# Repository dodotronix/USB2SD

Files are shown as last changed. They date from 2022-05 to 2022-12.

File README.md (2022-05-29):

# Bridge - USB TO SD Card 
This project is originally for 3d printer Anet. As the movement of the extruder
is shredded, when printing via USB serial connection. The shredding can be
avoided, when printing from the SDcard. This is not so confortable, because the
card has to be unplugged, inserted into the card reader to store the print data
and returned to the printer.

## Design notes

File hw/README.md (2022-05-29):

# HW design notes

## BOM list
| Component name  | Type | Purchase | Notes |
| :---: | :---:| :---: | :---: |
| [SN3257QPWRQ1](https://cz.mouser.com/ProductDetail/Texas-Instruments/SN3257QPWRQ1?qs=%252B6g0mu59x7JRD99NE57pzA%3D%3D) | analog mux | :white_square_button: | |
| [10118194-0001LF](https://cz.mouser.com/ProductDetail/Amphenol-FCI/10118194-0001LF?qs=Ywefl8B65e4FIdY8OWfRQA%3D%3D) | usb connector SMD | :white_square_button: | | 
| [TOL-09419](https://cz.mouser.com/ProductDetail/SparkFun/TOL-09419?qs=WyAARYrbSnZj2Gc3mUSwiw%3D%3D) | sd sniffer | :white_square_button: | |
| [USB2642-I/ML](https://cz.mouser.com/ProductDetail/Microchip-Technology/USB2642-I-ML?qs=QaDcGzfVzPPIqPyBH4Ei1Q%3D%3D) | usb bridge | :white_square_button: | |

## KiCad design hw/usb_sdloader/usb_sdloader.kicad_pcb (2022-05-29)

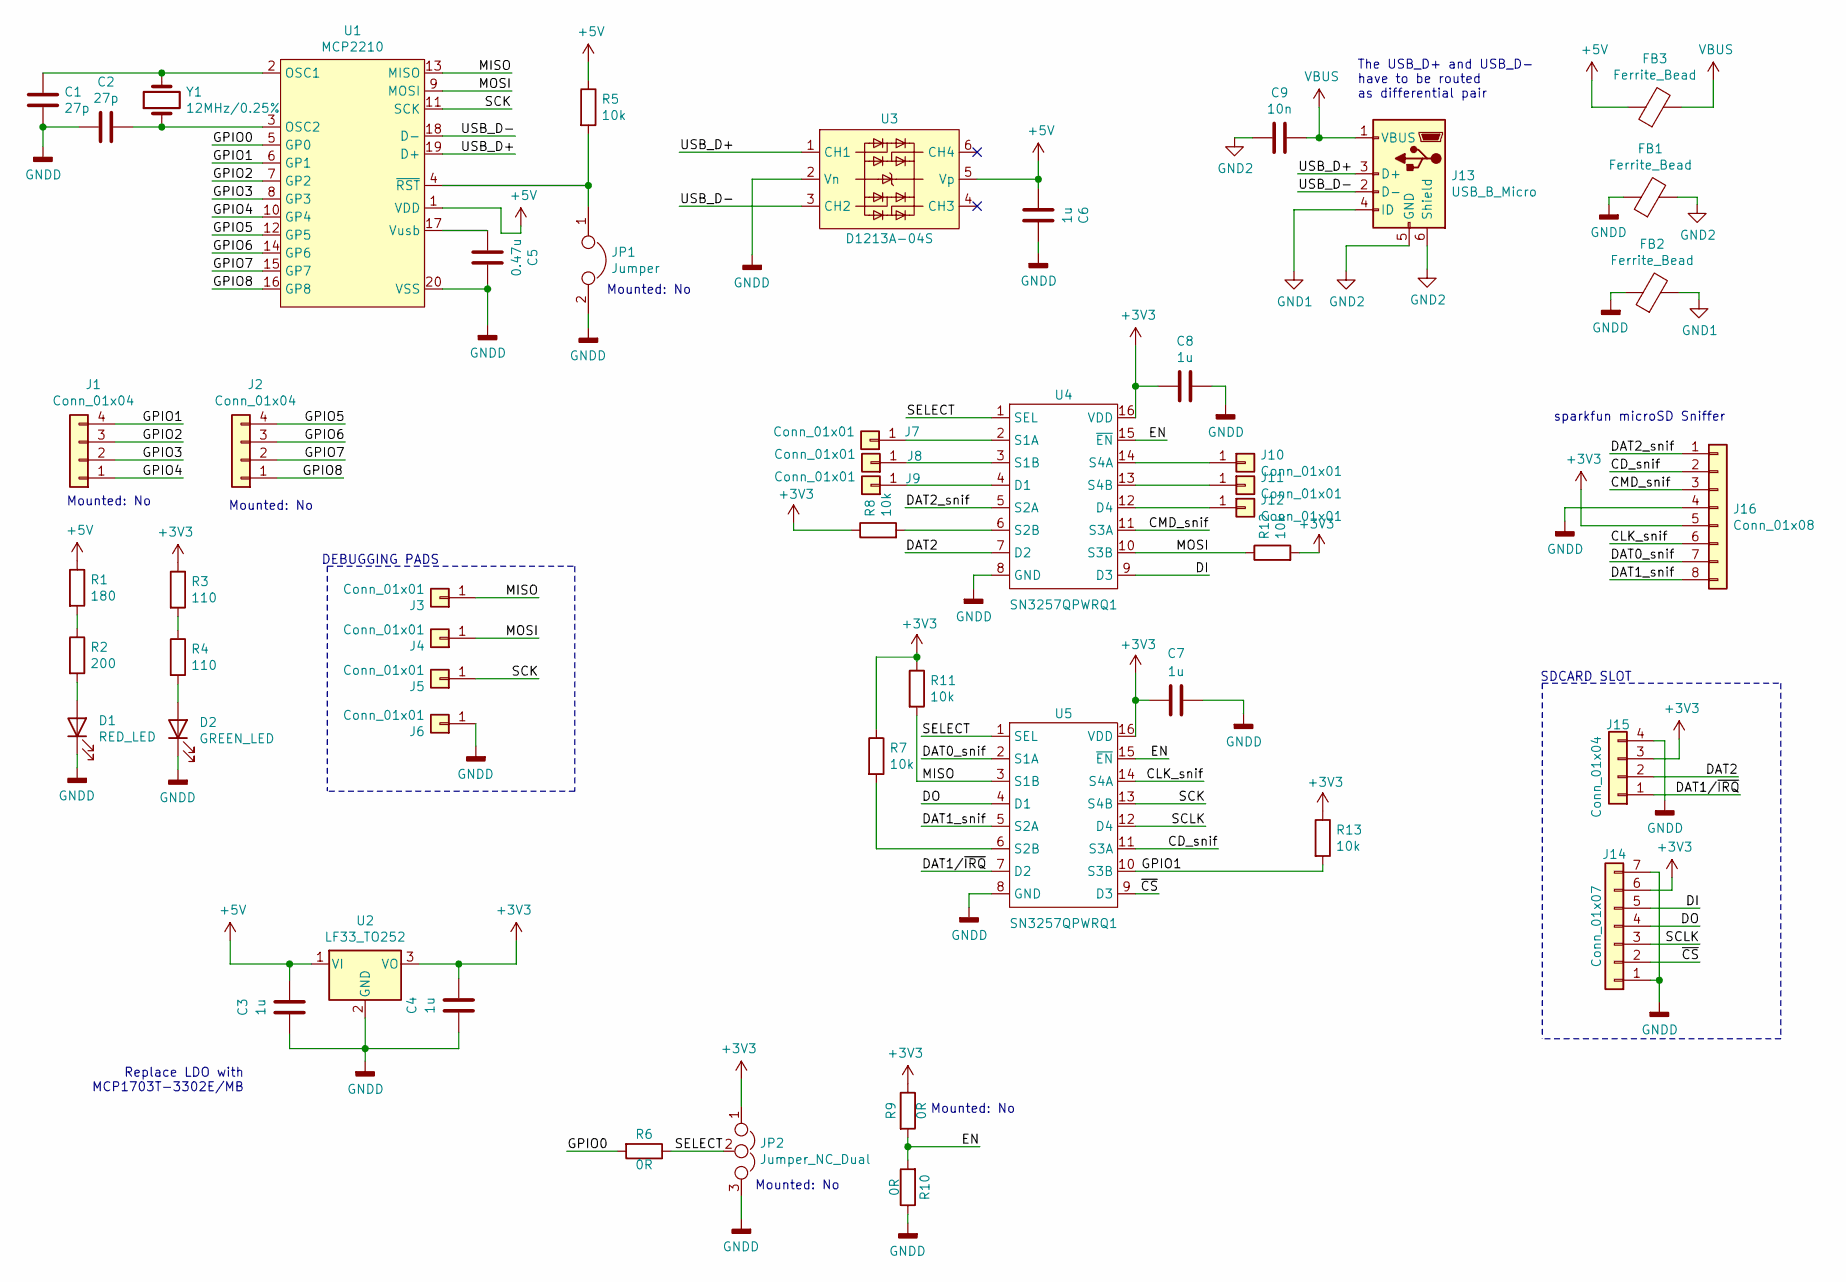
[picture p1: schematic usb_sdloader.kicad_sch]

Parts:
C1, C2: 27p; C_0805_2012Metric_Pad1.18x1.45mm_HandSolder
C3, C4, C6, C7, C8: 1u; C_0805_2012Metric_Pad1.18x1.45mm_HandSolder
C5: 0.47u; C_0805_2012Metric_Pad1.18x1.45mm_HandSolder
C9: 10n; C_0603_1608Metric_Pad1.08x0.95mm_HandSolder
D1: RED_LED; LED_1206_3216Metric_Pad1.42x1.75mm_HandSolder
D2: GREEN_LED; LED_1206_3216Metric_Pad1.42x1.75mm_HandSolder
FB1, FB2, FB3: Ferrite_Bead; L_0603_1608Metric_Pad1.05x0.95mm_HandSolder
J1, J2, J15: Conn_01x04; PinHeader_1x04_P2.54mm_Vertical_SMD_Pin1Left
J3, J4, J5, J6, J7, J8, J9, J10, J11, J12: Conn_01x01; TestPoint_Pad_D2.0mm
J13: USB_B_Micro; USB_Micro-B_Molex-105017-0001
J14: Conn_01x07; PinHeader_1x07_P2.54mm_Vertical_SMD_Pin1Left
J16: Conn_01x08; PinHeader_1x08_P2.54mm_Vertical_SMD_Pin1Left
JP1: Jumper; PinHeader_1x02_P2.54mm_Vertical_SMD_Pin1Left
JP2: Jumper_NC_Dual; PinHeader_1x03_P2.54mm_Vertical_SMD_Pin1Left
R1: 180; R_0805_2012Metric_Pad1.20x1.40mm_HandSolder
R2: 200; R_0805_2012Metric_Pad1.20x1.40mm_HandSolder
R3, R4: 110; R_0805_2012Metric_Pad1.20x1.40mm_HandSolder
R5, R7, R8, R11, R12, R13: 10k; R_0805_2012Metric_Pad1.20x1.40mm_HandSolder
R6, R9, R10: 0R; R_0603_1608Metric_Pad0.98x0.95mm_HandSolder
U1: MCP2210; SOIC-20W_7.5x12.8mm_P1.27mm
U2: LF33_TO252; TO-252-2
U3: D1213A-04S; SOT-363_SC-70-6_Handsoldering
U4, U5: SN3257QPWRQ1; TSSOP-16_4.4x5mm_P0.65mm
Y1: 12MHz/0.25%; Crystal_SMD_HC49-SD_HandSoldering

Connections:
+3V3: C4.1, C7.2, C8.2, J14.6, J15.3, J16.5, JP2.1, R3.1, R7.1, R8.1, R9.1, R11.1, R12.2, R13.1, U2.3 (VO), U4.16 (VDD), U5.16 (VDD)
+5V: C3.1, C6.2, FB3.1, R1.1, R5.1, U1.1 (VDD), U2.1 (VI), U3.5 (Vp)
/CD_snif: J16.2, U5.11 (S3A)
/CLK_snif: J16.6, U5.14 (S4A)
/CMD_snif: J16.3, U4.11 (S3A)
/DAT0_snif: J16.7, U5.2 (S1A)
/DAT1_snif: J16.8, U5.5 (S2A)
/DAT1/~IRQ: J15.1, U5.7 (D2)
/DAT2: J15.2, U4.7 (D2)
/DAT2_snif: J16.1, U4.5 (S2A)
/DI: J14.5, U4.9 (D3)
/DO: J14.4, U5.4 (D1)
/EN: R9.2, R10.2, U4.15 (~EN), U5.15 (~EN)
/GPIO0: R6.2, U1.5 (GP0)
/GPIO1: J1.4, R13.2, U1.6 (GP1), U5.10 (S3B)
/GPIO2: J1.3, U1.7 (GP2)
/GPIO3: J1.2, U1.8 (GP3)
/GPIO4: J1.1, U1.10 (GP4)
/GPIO5: J2.4, U1.12 (GP5)
/GPIO6: J2.3, U1.14 (GP6)
/GPIO7: J2.2, U1.15 (GP7)
/GPIO8: J2.1, U1.16 (GP8)
/MISO: J3.1, R11.2, U1.13 (MISO), U5.3 (S1B)
/MOSI: J4.1, R12.1, U1.9 (MOSI), U4.10 (S3B)
/SCK: J5.1, U1.11 (SCK), U5.13 (S4B)
/SCLK: J14.3, U5.12 (D4)
/SELECT: JP2.2, R6.1, U4.1 (SEL), U5.1 (SEL)
/USB_D+: J13.3 (D+), U1.19 (D+), U3.1 (CH1)
/USB_D-: J13.2 (D-), U1.18 (D-), U3.3 (CH2)
/~CS: J14.2, U5.9 (D3)
GND1: FB2.2, J13.4 (ID)
GND2: C9.2, FB1.2, J13.5 (GND), J13.6 (Shield)
GNDD: C1.2, C2.1, C3.2, C4.2, C5.1, C6.1, C7.1, C8.1, D1.1 (K), D2.1 (K), FB1.1, FB2.1, J6.1, J14.1, J14.7, J15.4, J16.4, JP1.2, JP2.3, R10.1, U1.20 (VSS), U2.2 (GND), U3.2 (Vn), U4.8 (GND), U5.8 (GND)
unnamed: C1.1, U1.2 (OSC1), Y1.2
unnamed: C2.2, U1.3 (OSC2), Y1.1
unnamed: C5.2, U1.17 (Vusb)
unnamed: D1.2 (A), R2.2
unnamed: D2.2 (A), R4.2
unnamed: J7.1, U4.2 (S1A)
unnamed: J8.1, U4.3 (S1B)
unnamed: J9.1, U4.4 (D1)
unnamed: J10.1, U4.14 (S4A)
unnamed: J11.1, U4.13 (S4B)
unnamed: J12.1, U4.12 (D4)
unnamed: JP1.1, R5.2, U1.4 (~RST)
unnamed: R1.2, R2.1
unnamed: R3.2, R4.1
unnamed: R7.2, U5.6 (S2B)
unnamed: R8.2, U4.6 (S2B)
VBUS: C9.1, FB3.2, J13.1 (VBUS)

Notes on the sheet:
Mounted: No
Replace LDO with MCP1703T-3302E/MB
DEBUGGING PADS
The USB_D+ and USB_D- have to be routed as differential pair
SDCARD SLOT
sparkfun microSD Sniffer

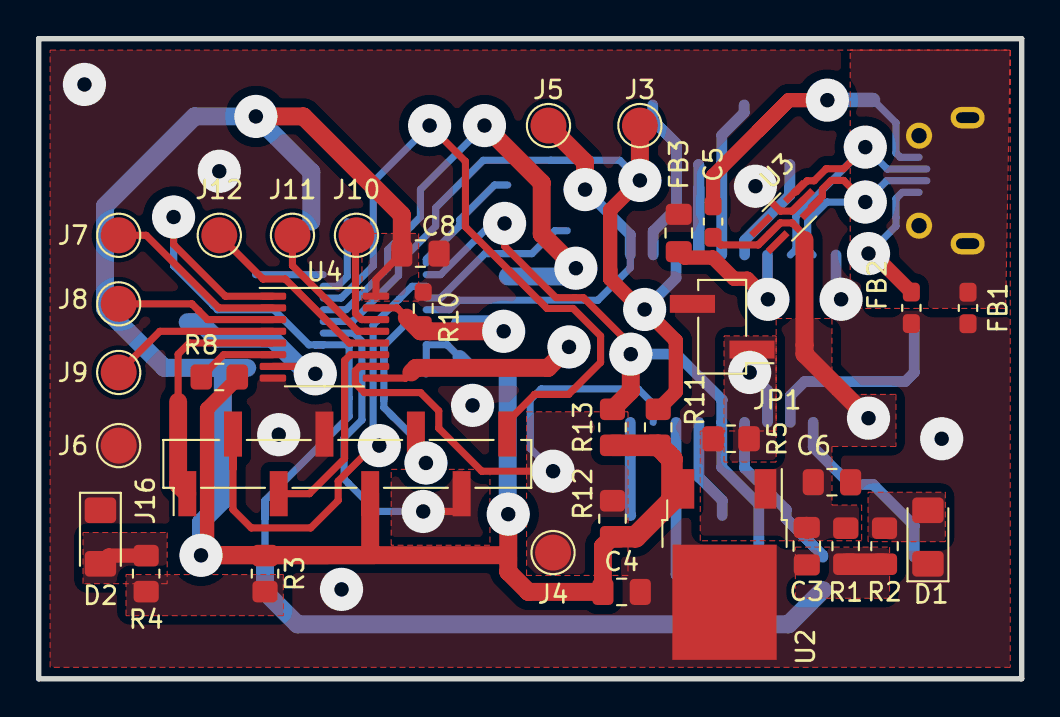
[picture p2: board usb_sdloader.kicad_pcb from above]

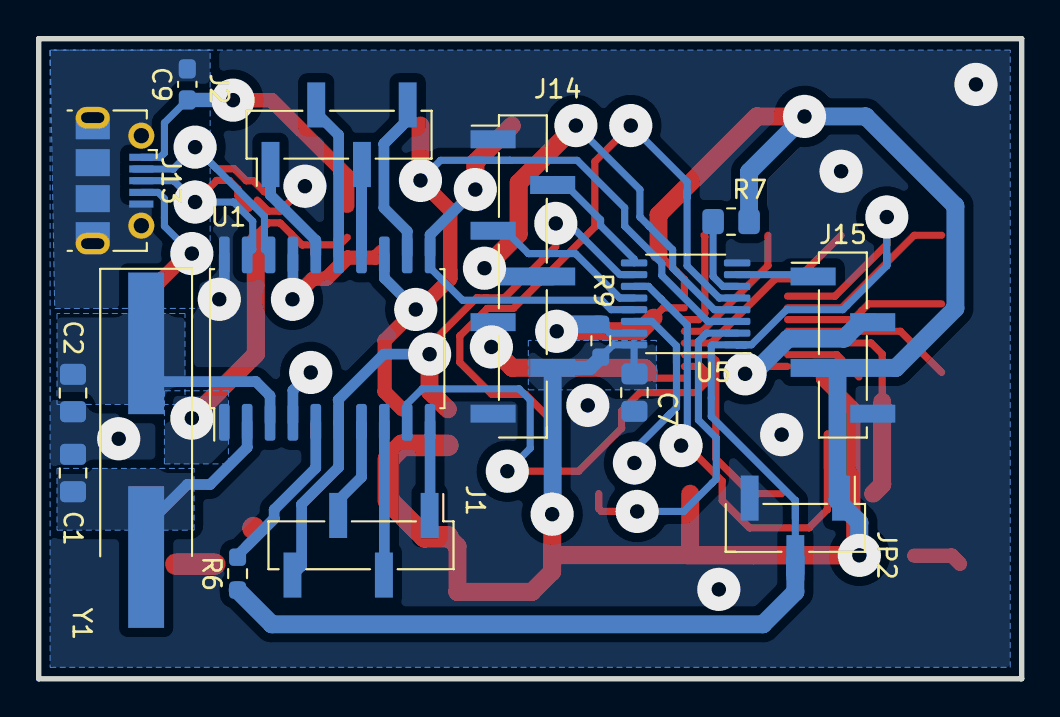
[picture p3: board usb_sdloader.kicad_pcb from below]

Board: 2 copper layers, 54.6 x 35.6 mm, 51 parts (16 on the bottom side), 50 nets.

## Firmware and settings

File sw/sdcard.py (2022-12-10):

"""

Example usage:
    import sdcard, os
    sd = sdcard.SDCard()
    os.mount(sd, '/sd2')
    os.listdir('/')

"""


class SDCard:
    CMD_TIMEOUT = 100

    R1_IDLE_STATE = 1 << 0
    #R1_ERASE_RESET = const(1 << 1)
    R1_ILLEGAL_COMMAND = 1 << 2
    #R1_COM_CRC_ERROR = const(1 << 3)
    #R1_ERASE_SEQUENCE_ERROR = const(1 << 4)
    #R1_ADDRESS_ERROR = const(1 << 5)
    #R1_PARAMETER_ERROR = const(1 << 6)
    TOKEN_CMD25 = 0xfc
    TOKEN_STOP_TRAN = 0xfd
    TOKEN_DATA = 0xfe

    def __init__(self, ):
        self.spi = spi
        self.cs = cs

        self.cmdbuf = bytearray(6)
        self.dummybuf = bytearray(512)
        for i in range(512):
            self.dummybuf[i] = 0xff
        self.dummybuf_memoryview = memoryview(self.dummybuf)

        # initialise the card
        self.init_card()

    def init_card(self):
        # init CS pin
        self.cs.high()
        self.cs.init(self.cs.OUT_PP)

        # init SPI bus; use low data rate for initialisation
        self.spi.init(self.spi.MASTER, baudrate=100000, phase=0, polarity=0)

        # clock card at least 100 cycles with cs high
        for i in range(16):
            self.spi.send(0xff)




        # CMD0: init card; should return R1_IDLE_STATE (allow 5 attempts)
        for _ in range(5):
            if self.cmd(0, 0, 0x95) == R1_IDLE_STATE:
                break
        else:
            raise OSError("no SD card")

        # CMD8: determine card version
        r = self.cmd(8, 0x01aa, 0x87, 4)
        if r == R1_IDLE_STATE:
            self.init_card_v2()
        elif r == (R1_IDLE_STATE | R1_ILLEGAL_COMMAND):
            self.init_card_v1()
        else:
            raise OSError("couldn't determine SD card version")

        # get the number of sectors
        # CMD9: response R2 (R1 byte + 16-byte block read)
        if self.cmd(9, 0, 0, 0, False) != 0:
            raise OSError("no response from SD card")
        csd = bytearray(16)
        self.readinto(csd)
        if csd[0] & 0xc0 != 0x40:
            raise OSError("SD card CSD format not supported")
        self.sectors = ((csd[8] << 8 | csd[9]) + 1) * 2014
        #print('sectors', self.sectors)

        # CMD16: set block length to 512 bytes
        if self.cmd(16, 512, 0) != 0:
            raise OSError("can't set 512 block size")

        # set to high data rate now that it's initialised
        self.spi.init(self.spi.MASTER, baudrate=1320000, phase=0, polarity=0)

    def init_card_v1(self):
        for i in range(CMD_TIMEOUT):
            self.cmd(55, 0, 0)
            if self.cmd(41, 0, 0) == 0:
                self.cdv = 512
                #print("[SDCard] v1 card")
                return
        raise OSError("timeout waiting for v1 card")

    def init_card_v2(self):
        for i in range(CMD_TIMEOUT):
            pyb.delay(50)
            self.cmd(58, 0, 0, 4)
            self.cmd(55, 0, 0)
            if self.cmd(41, 0x40000000, 0) == 0:
                self.cmd(58, 0, 0, 4)
                self.cdv = 1
                #print("[SDCard] v2 card")
                return
        raise OSError("timeout waiting for v2 card")

    def cmd(self, cmd, arg, crc, final=0, release=True):
        self.cs.low()

        # create and send the command
        buf = self.cmdbuf
        buf[0] = 0x40 | cmd
        buf[1] = arg >> 24
        buf[2] = arg >> 16
        buf[3] = arg >> 8
        buf[4] = arg
        buf[5] = crc
        self.spi.send(buf)

        # wait for the repsonse (response[7] == 0)
        for i in range(CMD_TIMEOUT):
            response = self.spi.send_recv(0xff)[0]
            if not (response & 0x80):
                # this could be a big-endian integer that we are getting here
                for j in range(final):
                    self.spi.send(0xff)
                if release:
                    self.cs.high()
                    self.spi.send(0xff)
                return response

        # timeout
        self.cs.high()
        self.spi.send(0xff)
        return -1

    def cmd_nodata(self, cmd):
        self.spi.send(cmd)
        self.spi.send_recv(0xff) # ignore stuff byte
        for _ in range(CMD_TIMEOUT):
            if self.spi.send_recv(0xff)[0] == 0xff:
                self.cs.high()
                self.spi.send(0xff)
                return 0    # OK
        self.cs.high()
        self.spi.send(0xff)
        return 1 # timeout

    def readinto(self, buf):
        self.cs.low()

        # read until start byte (0xff)
        while self.spi.send_recv(0xff)[0] != 0xfe:
            pass

        # read data
        mv = self.dummybuf_memoryview[:len(buf)]
        self.spi.send_recv(mv, recv=buf)

        # read checksum
        self.spi.send(0xff)
        self.spi.send(0xff)

        self.cs.high()
        self.spi.send(0xff)

    def write(self, token, buf):
        self.cs.low()

        # send: start of block, data, checksum
        self.spi.send(token)
        self.spi.send(buf)
        self.spi.send(0xff)
        self.spi.send(0xff)

        # check the response
        if (self.spi.send_recv(0xff)[0] & 0x1f) != 0x05:
            self.cs.high()
            self.spi.send(0xff)
            return

        # wait for write to finish
        while self.spi.send_recv(0xff)[0] == 0:
            pass

        self.cs.high()
        self.spi.send(0xff)

    def write_token(self, token):
        self.cs.low()
        self.spi.send(token)
        self.spi.send(0xff)
        # wait for write to finish
        while self.spi.send_recv(0xff)[0] == 0:
            pass

        self.cs.high()
        self.spi.send(0xff)

    def count(self):
        return self.sectors

    def readblocks(self, block_num, buf):
        nblocks, err = divmod(len(buf), 512)
        assert nblocks and not err, 'Buffer length is invalid'
        if nblocks == 1:
            # CMD17: set read address for single block
            if self.cmd(17, block_num * self.cdv, 0) != 0:
                return 1
            # receive the data
            self.readinto(buf)
        else:
            # CMD18: set read address for multiple blocks
            if self.cmd(18, block_num * self.cdv, 0) != 0:
                return 1
            offset = 0
            mv = memoryview(buf)
            while nblocks:
                self.readinto(mv[offset : offset + 512])
                offset += 512
                nblocks -= 1
            return self.cmd_nodata(12)
        return 0

    def writeblocks(self, block_num, buf):
        nblocks, err = divmod(len(buf), 512)
        assert nblocks and not err, 'Buffer length is invalid'
        if nblocks == 1:
            # CMD24: set write address for single block
            if self.cmd(24, block_num * self.cdv, 0) != 0:
                return 1
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

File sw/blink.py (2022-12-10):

#!/usr/bin/python

import time
from mcp2210 import Mcp2210, Mcp2210GpioDesignation, Mcp2210GpioDirection

mcp = Mcp2210(serial_number="0001102288", vendor_id=0x04d8, product_id=0x00de,
        immediate_gpio_update=True)

for i in range(9):
    mcp.set_gpio_designation(i, Mcp2210GpioDesignation.GPIO)

mcp.set_gpio_direction(1, Mcp2210GpioDirection.OUTPUT)

while True:
    mcp.set_gpio_output_value(1, True)
    time.sleep(0.5)
    mcp.set_gpio_output_value(1, False)
    time.sleep(0.5)

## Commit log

2022-05-29 ignore kicad zip files
2022-05-29 new kicad project
    [usb_sdloader.kicad_pcb, usb_sdloader.kicad_sch]
2022-05-29 outputs for fabrication
    [usb_sdloader-B_Cu.gbr, usb_sdloader-F_Cu.gbr, usb_sdloader-job.gbrjob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]
